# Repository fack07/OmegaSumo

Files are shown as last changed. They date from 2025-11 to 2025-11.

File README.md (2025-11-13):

# 🤖 Robô Lutador de Sumô Autônomo de 3 kg

Este repositório contém o projeto **Omega Sumo**, um robô autônomo de sumô de 3 kg, desenvolvido como parte do **Trabalho de Conclusão de Curso (TCC)** em Engenharia de Computação da UTFPR – Campus Pato Branco.

O projeto aborda a **atualização de hardware e software** do robô, com foco na implementação de um **sistema supervisório baseado em SED (Sistemas a Eventos Discretos)**, visando estratégias eficientes e melhoria de desempenho em combate.

---

## ⚙️ Estrutura do Repositório

| Pasta | Descrição |
|---|---|
| [`Firmware/`](./Firmware) | Contém o código embarcado para o microcontrolador STM32F407VET6, implementando controle de sensores, motores e o supervisor em tempo real. |
| [`Supervisor/`](./Supervisor) | Contém o modelo supervisório desenvolvido no Supremica (`omega_sumo.wmod`), compactado em `.zip`, reunindo as plantas, especificações e supervisor. |
| [`PCB/`](./PCB) | Projeto eletrônico do robô, incluindo esquemáticos e layout da placa. |

---
## 🧰 Ferramentas Utilizadas
- [Supremica](https://www.supremica.org) – Modelagem e síntese supervisória (uso acadêmico)  
- [STM32CubeIDE](https://www.st.com/en/development-tools/stm32cubeide.html) – Desenvolvimento e compilação do firmware  
- [Autodesk EAGLE](https://www.autodesk.com/products/eagle/overview) – Desenvolvimento do projeto eletrônico e layout de PCB  
- [GitHub](https://github.com/) – Controle de versão e compartilhamento do projeto  

---

## 📜 Licença e Uso
Este projeto foi desenvolvido para fins **acadêmicos e de pesquisa**.  
Os arquivos gerados pelo Supremica são distribuídos conforme sua licença de uso educativo.  
O código-fonte embarcado e o projeto eletrônico podem ser reutilizados livremente para fins não comerciais, com a devida citação do autor.

---

## 👤 Autor

**Fabio Kinukawa**  
Engenharia de Computação — UTFPR

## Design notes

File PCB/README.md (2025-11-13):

# ⚡ Projeto Eletrônico – Omega Sumo (PCB)

Esta pasta contém o **projeto eletrônico** do robô autônomo de sumô **Omega Sumo**, desenvolvido no contexto do Trabalho de Conclusão de Curso (TCC) em Engenharia de Computação da UTFPR – Câmpus Pato Branco.

O circuito foi projetado no **Autodesk EAGLE 9.x**, abrangendo os módulos de potência, controle e sensores do robô.  
O objetivo do projeto é fornecer uma base estável e modular para o sistema embarcado do robô, compatível com o microcontrolador **STM32F407VET6**.

---

## 🧩 Estrutura dos Arquivos

| Arquivo | Descrição |
|---|---|
| `OmegaSumo.sch` | Esquemático principal do circuito eletrônico, contendo o microcontrolador, drivers de motor, sensores e interfaces de comunicação. |
| `OmegaSumo.brd` | Layout da placa de circuito impresso (PCB), desenvolvido a partir do esquemático. |
| `pcb_top.png` | Imagens 2D e/ou 3D da placa geradas no EAGLE. |
| `pcb_bottom.png` | Imagens 2D e/ou 3D da placa geradas no EAGLE. |
| `OmegaSumo_PCB.zip` | Arquivo compactado contendo todos os arquivos nativos do projeto EAGLE. |

---

## ⚙️ Especificações Técnicas

- **Software:** Autodesk EAGLE 9.x  
- **Camadas:** 2 (dupla face)  
- **Dimensões aproximadas:** conforme layout (otimizado para o chassi do robô Omega Sumo)  
- **Alimentação:** 7,4 V (Li-Po 2S)  
- **Tensão lógica:** 3,3 V  
- **Controlador principal:** STM32F407VET6  
- **Interfaces principais:** sensores IR, sensores de linha, drivers de motor, botão de start, LEDs de status  

---

## 🛠️ Como Abrir o Projeto

1. Instale o **Autodesk EAGLE** (versão 9.x ou superior).  
2. Baixe e extraia o arquivo [`OmegaSumo_PCB.zip`](./OmegaSumo_PCB.zip).  
3. Abra o arquivo `OmegaSumo.sch` no EAGLE.  
4. Verifique o esquemático e sincronize com o layout (`OmegaSumo.brd`) caso necessário.  
5. Gere os arquivos Gerber para fabricação em **File → CAM Processor → Generate Gerbers**.

---

## ⚠️ Boas Práticas de Projeto

- Mantenha trilhas de potência largas (≥ 1 mm para corrente de motor).  
- Utilize planos de terra (`GND Plane`) para reduzir ruído e interferência.  
- Separe áreas de potência e lógica no layout.  
- Verifique a orientação de componentes polarizados (diodos, capacitores eletrolíticos, conectores).  
- Sempre execute o **DRC (Design Rule Check)** antes da geração dos Gerbers.

---

## 📜 Licença

Este projeto é distribuído para **fins acadêmicos e de pesquisa**, sendo permitido seu uso como referência em estudos e trabalhos relacionados a sistemas embarcados e robótica móvel.  
É proibido o uso comercial sem autorização do autor.

---

## ✍️ Autor

**Fabio Kinukawa**  
Trabalho de Conclusão de Curso – Engenharia de Computação  
UTFPR – Universidade Tecnológica Federal do Paraná  
Equipe: **PatoBots**

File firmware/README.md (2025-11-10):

# 🧠 Firmware – Robô de Sumô Autônomo (Omega Sumo)

Este diretório contém o **firmware embarcado** desenvolvido para o robô de sumô autônomo de 3 kg.  
O código foi implementado em **C** utilizando o **STM32CubeIDE**, com foco em controle de motores, leitura de sensores e execução das ações determinadas pelo supervisor.

---

## ⚙️ Estrutura
- `Core/` – Código principal gerado pelo CubeIDE (funções do sistema embarcado).  
- `Drivers/` – Bibliotecas de periféricos do STM32.  
- `Src/` e `Inc/` – Arquivos de código-fonte e cabeçalhos do projeto.  
- `STM32F407VETX_FLASH.ld` – Script de linkagem do microcontrolador.  

---

## 🧩 Plataforma
- **Microcontrolador:** STM32F407VET6  
- **IDE:** STM32CubeIDE  
- **Linguagem:** C  
- **Compilador:** ARM GCC  
- **Memória ocupada:** ~352 KB de Flash  

---

## 🔗 Integração com o Supervisor
O firmware implementa uma **máquina de estados Meely** gerada a partir do autômato supervisor, compilada e integrada ao código principal.  
A comunicação entre o supervisor e o firmware ocorre por meio de variáveis de evento (entradas e saídas do sistema).

---

## 🧰 Compilação e Gravação
1. Abra o projeto no **STM32CubeIDE**.  
2. Selecione a placa alvo `STM32F407VET6`.  
3. Compile (`Project → Build Project`).  
4. Faça o upload via **ST-LINK/V2** ou programador compatível.

---

## 📄 Licença
Uso educacional e acadêmico.  
Parte do código foi gerado automaticamente pelo STM32CubeIDE.  
Distribuição permitida apenas para fins de pesquisa e documentação.

---

## ✍️ Autor
**Fabio Kinukawa**  
Trabalho de Conclusão de Curso – Engenharia de Computação  
UTFPR – Universidade Tecnológica Federal do Paraná
Campus Pato Branco

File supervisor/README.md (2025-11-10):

# 🧩 Supervisor – Controle Supervisório (Omega Sumo)

Este diretório contém o **modelo supervisório completo** do robô de sumô autônomo de 3 kg, desenvolvido como parte do Trabalho de Conclusão de Curso de Engenharia de Computação (UTFPR).

---

## ⚙️ Descrição
O arquivo principal `omega_sumo.wmod` foi criado utilizando o software **Supremica** e reúne toda a modelagem do sistema, incluindo:

- **Plantas**: modelagem modular dos componentes do robô;  
- **Especificações**: definição das regras e estratégias de controle;  
- **Supervisor**: resultado da **síntese supervisória** após a composição síncrona entre plantas e especificações.

O modelo é usado para gerar o **supervisor implementável**, posteriormente convertido para uma **máquina de estados Moore** e integrado ao firmware do microcontrolador STM32.

---

## 🧠 Ferramenta Utilizada
- **Supremica** – Software para modelagem e análise de sistemas a eventos discretos (uso acadêmico e de pesquisa).  

---

## 🧩 Formato do Arquivo
- `omega_sumo.wmod` – Projeto do Supremica contendo todos os autômatos do sistema.

O arquivo pode ser aberto diretamente no Supremica para visualização, edição e execução da síntese supervisória.

---

## 📜 Observação de Licença
O modelo foi desenvolvido com o Supremica, software **gratuito para uso acadêmico e de pesquisa**.  
Nenhum componente proprietário do Supremica é distribuído neste repositório.

---

## ✍️ Autor
**Fabio Kinukawa**  
Trabalho de Conclusão de Curso – Engenharia de Computação  
UTFPR – Universidade Tecnológica Federal do Paraná
Campus Pato Branco

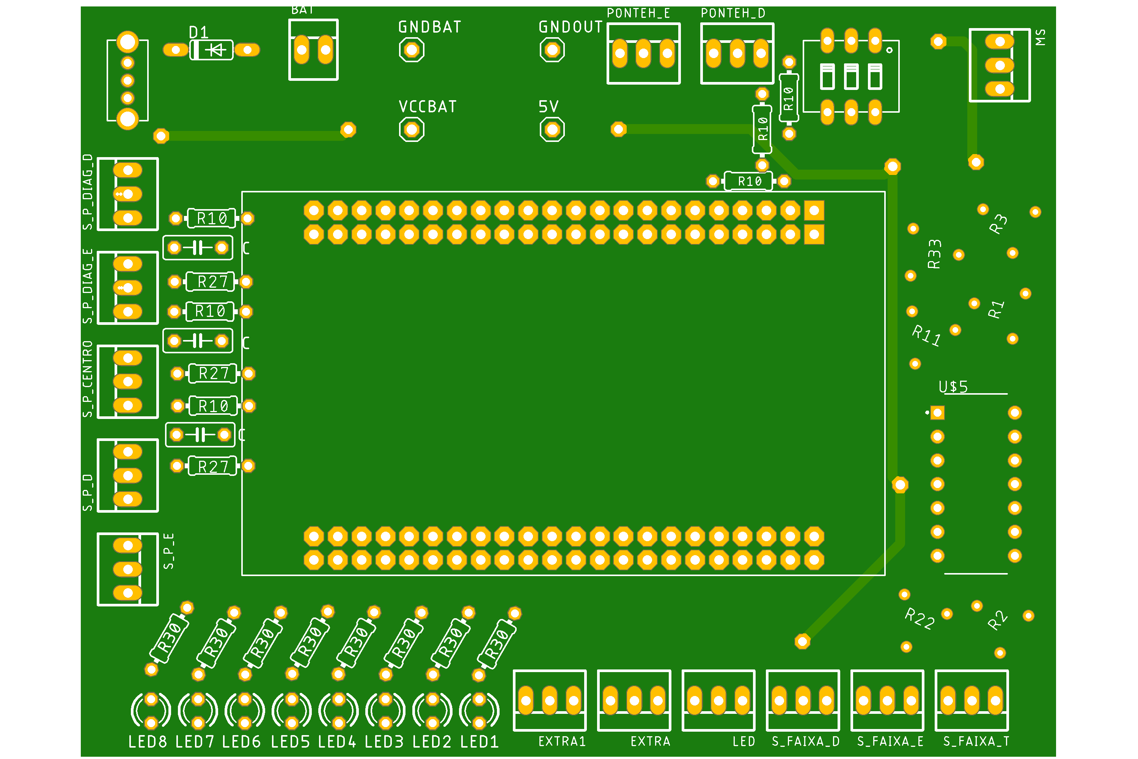
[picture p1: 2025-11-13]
PCB/pcb_top.png

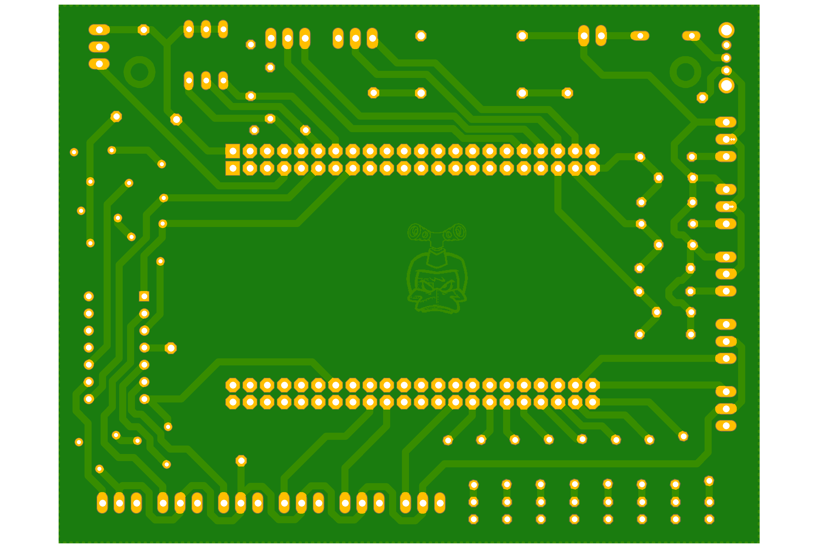
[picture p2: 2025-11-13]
PCB/pcb_bottom.png

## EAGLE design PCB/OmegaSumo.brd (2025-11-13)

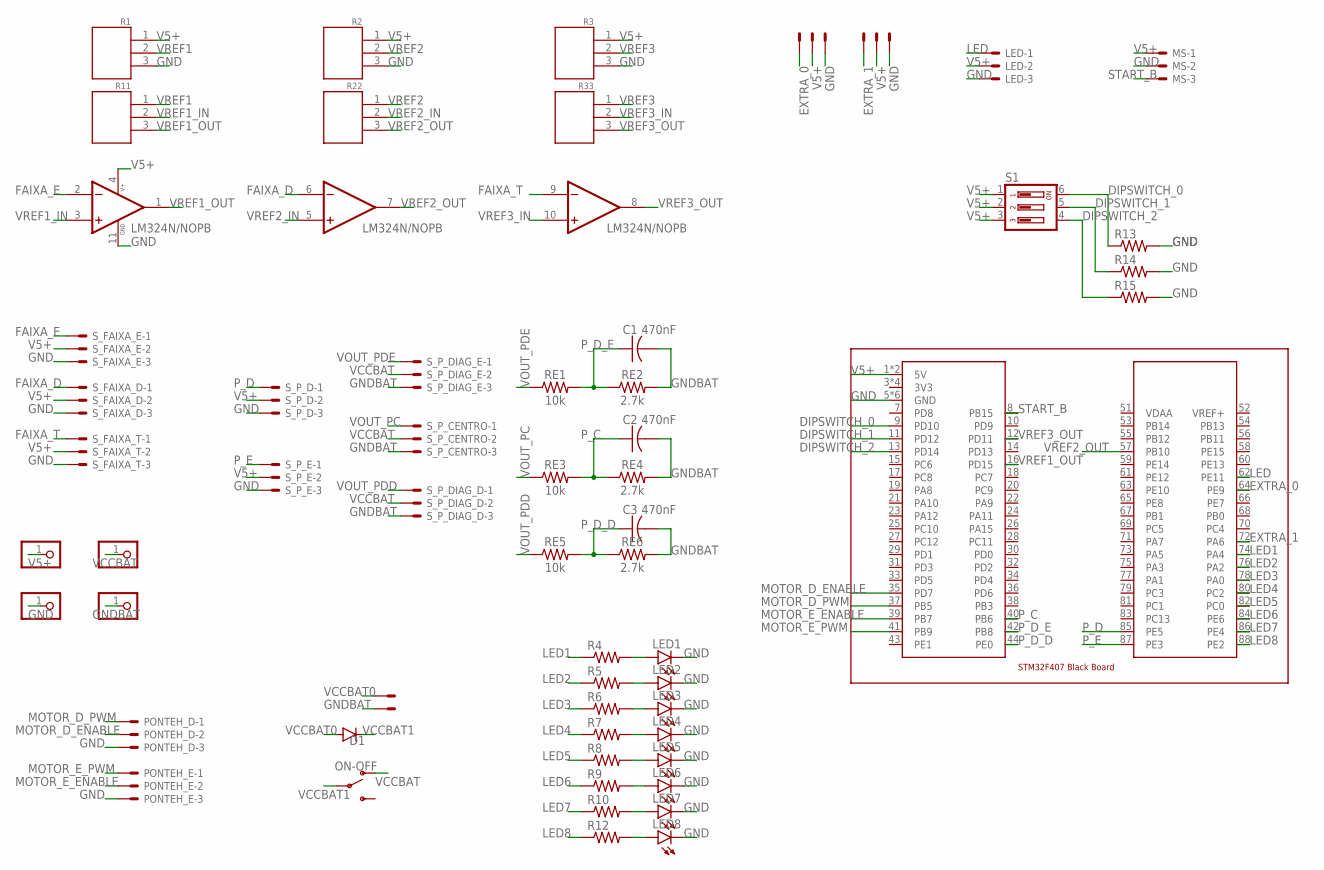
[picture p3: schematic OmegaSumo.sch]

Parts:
5V: PINHD-1X1; 1X01
BAT: 22-23-2021
C1, C2, C3: 470nF; C050-025X075
D1: 1N4148DO35-7; DO35-7
EXTRA, EXTRA1: 22-23-2031
GNDBAT: PINHD-1X1; 1X01
GNDOUT: PINHD-1X1; 1X01
LED: 22-23-2031
LED1, LED2, LED3, LED4, LED5, LED6, LED7, LED8: LED3MM
MS: 22-23-2031
ON-OFF: SWITCH-SPDT-PTH-8.6X4.3MM-LOCK; SWITCH_SPDT_8.6X4.3MM_LOCK
PONTEH_D: 22-23-2031
PONTEH_E: 22-23-2031
R1, R2, R3, R11, R22, R33: RM065
R4, R5, R6, R7, R8, R9, R10, R12, R13, R14, R15: R-US_0204/7; 0204/7
RE1, RE3, RE5: 10k; 0204/7
RE2, RE4, RE6: 2.7k; 0204/7
S1: DIP03YL
S_FAIXA_D: 22-23-2031
S_FAIXA_E: 22-23-2031
S_FAIXA_T: 22-23-2031
S_P_CENTRO: 22-23-2031
S_P_D: 22-23-2031
S_P_DIAG_D: 22-23-2031
S_P_DIAG_E: 22-23-2031
S_P_E: 22-23-2031
U$5: LM324N/NOPB; DIP825W47P254L1917H533Q14
U$6: LIB1BLACK_BOARD; STM32F407
VCCBAT: PINHD-1X1; 1X01

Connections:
DIPSWITCH_0: R13.1, S1.6, U$6.9 (PD10)
DIPSWITCH_1: R14.1, S1.5, U$6.11 (PD12)
DIPSWITCH_2: R15.1, S1.4, U$6.13 (PD14)
EXTRA_0: EXTRA.1, U$6.64 (PE9)
EXTRA_1: EXTRA1.1, U$6.72 (PA6)
FAIXA_D: S_FAIXA_D.1, U$5.6 (2IN-)
FAIXA_E: S_FAIXA_E.1, U$5.2 (1IN-)
FAIXA_T: S_FAIXA_T.1, U$5.9 (3IN-)
GND: EXTRA.3, EXTRA1.3, GNDOUT.1, LED.3, LED1.K (C), LED2.K (C), LED3.K (C), LED4.K (C), LED5.K (C), LED6.K (C), LED7.K (C), LED8.K (C), MS.2, PONTEH_D.3, PONTEH_E.3, R1.3, R2.3, R3.3, R13.2, R14.2, R15.2, S_FAIXA_D.3, S_FAIXA_E.3, S_FAIXA_T.3, S_P_D.3, S_P_E.3, U$5.11 (GND), U$6.5 (GND), U$6.6 (GND), U$6.47 (GND), U$6.48 (GND), U$6.49 (GND), U$6.50 (GND)
GNDBAT: BAT.2, C1.2, C2.2, C3.2, GNDBAT.1, RE2.2, RE4.2, RE6.2, S_P_CENTRO.3, S_P_DIAG_D.3, S_P_DIAG_E.3
LED: LED.1, U$6.62 (PE11)
LED1: R4.1, U$6.74 (PA4)
LED2: R5.1, U$6.76 (PA2)
LED3: R6.1, U$6.78 (PA0)
LED4: R7.1, U$6.80 (PC2)
LED5: R8.1, U$6.82 (PC0)
LED6: R9.1, U$6.84 (PE6)
LED7: R10.1, U$6.86 (PE4)
LED8: R12.1, U$6.88 (PE2)
MOTOR_D_ENABLE: PONTEH_D.2, U$6.35 (PD7)
MOTOR_D_PWM: PONTEH_D.1, U$6.37 (PB5)
MOTOR_E_ENABLE: PONTEH_E.2, U$6.39 (PB7)
MOTOR_E_PWM: PONTEH_E.1, U$6.41 (PB9)
unnamed: LED1.A, R4.2
unnamed: LED2.A, R5.2
unnamed: LED3.A, R6.2
unnamed: LED4.A, R7.2
unnamed: LED5.A, R8.2
unnamed: LED6.A, R9.2
unnamed: LED7.A, R10.2
unnamed: LED8.A, R12.2
P_C: C2.1, RE3.2, RE4.1, U$6.40 (PB6)
P_D: S_P_D.1, U$6.85 (PE5)
P_D_D: C3.1, RE5.2, RE6.1, U$6.44 (PE0)
P_D_E: C1.1, RE1.2, RE2.1, U$6.42 (PB8)
P_E: S_P_E.1, U$6.87 (PE3)
START_B: MS.3, U$6.8 (PB15)
V5+: 5V.1, EXTRA.2, EXTRA1.2, LED.2, MS.1, R1.1, R2.1, R3.1, S1.1, S1.2, S1.3, S_FAIXA_D.2, S_FAIXA_E.2, S_FAIXA_T.2, S_P_D.2, S_P_E.2, U$5.4 (V+), U$6.1 (5V), U$6.2 (5V)
VCCBAT: ON-OFF.1 (O), S_P_CENTRO.2, S_P_DIAG_D.2, S_P_DIAG_E.2, VCCBAT.1
VCCBAT0: BAT.1, D1.A
VCCBAT1: D1.C, ON-OFF.2
VOUT_PC: RE3.1, S_P_CENTRO.1
VOUT_PDD: RE5.1, S_P_DIAG_D.1
VOUT_PDE: RE1.1, S_P_DIAG_E.1
VREF1: R1.2, R11.1
VREF1_IN: R11.2, U$5.3 (1IN+)
VREF1_OUT: R11.3, U$5.1 (1OUT), U$6.16 (PD15)
VREF2: R2.2, R22.1
VREF2_IN: R22.2, U$5.5 (2IN+)
VREF2_OUT: R22.3, U$5.7 (2OUT), U$6.57 (PB10)
VREF3: R3.2, R33.1
VREF3_IN: R33.2, U$5.10 (3IN+)
VREF3_OUT: R33.3, U$5.8 (3OUT), U$6.12 (PD11)

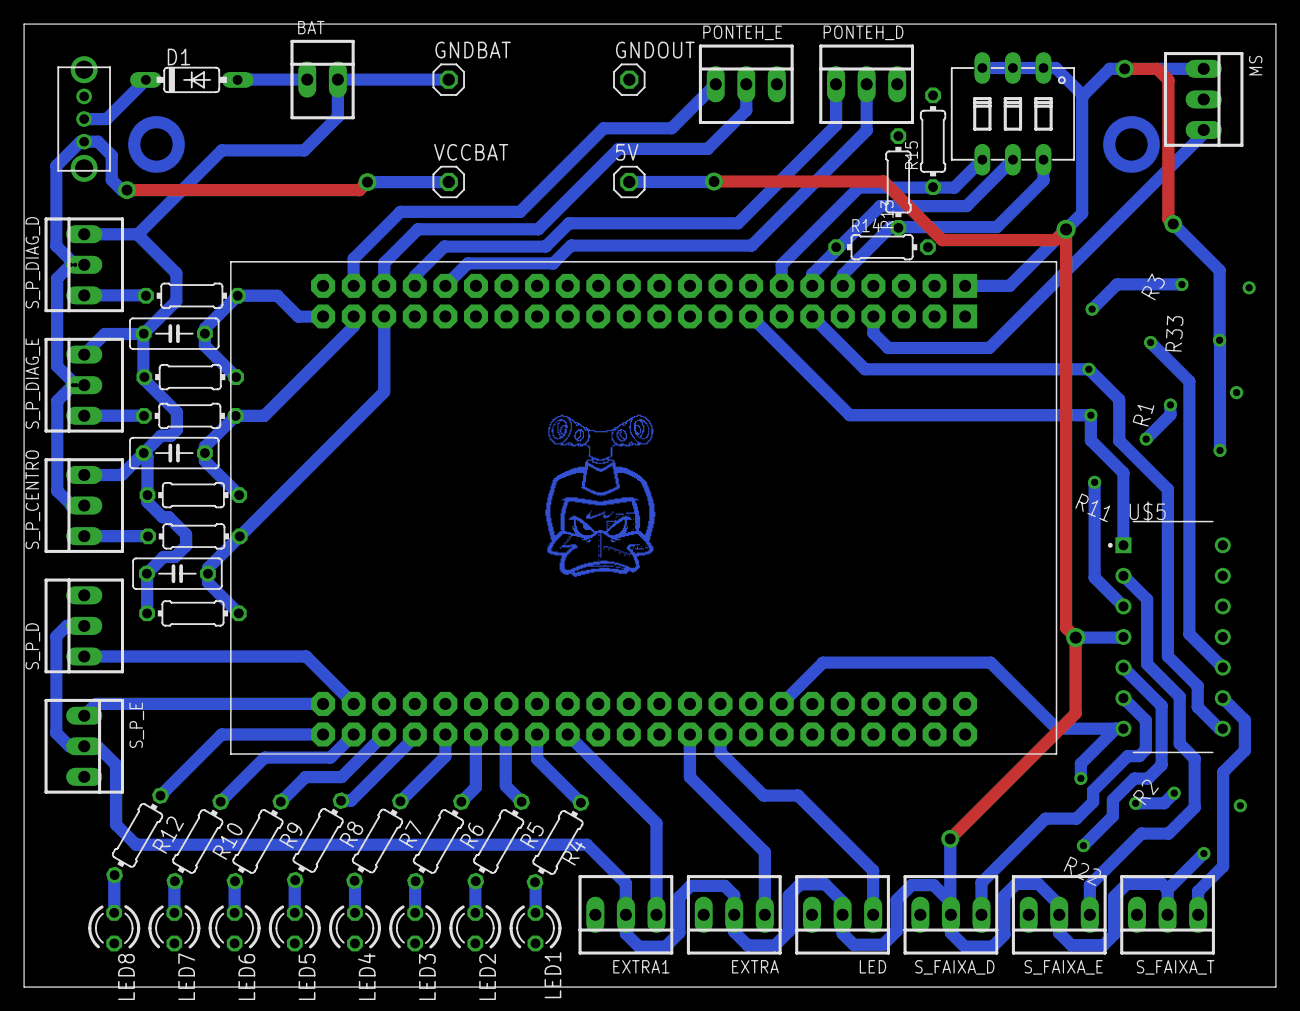
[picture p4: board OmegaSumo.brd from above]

Board: 2 copper layers, 104.0 x 80.0 mm, 58 parts (0 on the bottom side), 53 nets.

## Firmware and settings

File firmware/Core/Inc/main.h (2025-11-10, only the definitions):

#define LED1_Pin GPIO_PIN_2
#define LED1_GPIO_Port GPIOE
#define PRESENCA5_Pin GPIO_PIN_3
#define PRESENCA5_GPIO_Port GPIOE
#define PRESENCA5_EXTI_IRQn EXTI3_IRQn
#define LED2_Pin GPIO_PIN_4
#define LED2_GPIO_Port GPIOE
#define PRESENCA1_Pin GPIO_PIN_5
#define PRESENCA1_GPIO_Port GPIOE
#define PRESENCA1_EXTI_IRQn EXTI9_5_IRQn
#define LED3_Pin GPIO_PIN_6
#define LED3_GPIO_Port GPIOE
#define LED4_Pin GPIO_PIN_0
#define LED4_GPIO_Port GPIOC
#define LED5_Pin GPIO_PIN_2
#define LED5_GPIO_Port GPIOC
#define LED6_Pin GPIO_PIN_0
#define LED6_GPIO_Port GPIOA
#define LED7_Pin GPIO_PIN_2
#define LED7_GPIO_Port GPIOA
#define LED8_Pin GPIO_PIN_4
#define LED8_GPIO_Port GPIOA
#define BANDEIRA_Pin GPIO_PIN_6
#define BANDEIRA_GPIO_Port GPIOA
#define FAIXA2_Pin GPIO_PIN_10
#define FAIXA2_GPIO_Port GPIOB
#define FAIXA2_EXTI_IRQn EXTI15_10_IRQn
#define MICROSTART_Pin GPIO_PIN_15
#define MICROSTART_GPIO_Port GPIOB
#define DIPS0_Pin GPIO_PIN_10
#define DIPS0_GPIO_Port GPIOD
#define FAIXA3_Pin GPIO_PIN_11
#define FAIXA3_GPIO_Port GPIOD
#define FAIXA3_EXTI_IRQn EXTI15_10_IRQn
#define DIPS1_Pin GPIO_PIN_12
#define DIPS1_GPIO_Port GPIOD
#define DIPS2_Pin GPIO_PIN_14
#define DIPS2_GPIO_Port GPIOD
#define FAIXA1_Pin GPIO_PIN_15
#define FAIXA1_GPIO_Port GPIOD
#define FAIXA1_EXTI_IRQn EXTI15_10_IRQn
#define MOTOR_D_ENABLE_Pin GPIO_PIN_7
#define MOTOR_D_ENABLE_GPIO_Port GPIOD
#define MOTOR_E_ENABLE_Pin GPIO_PIN_5
#define MOTOR_E_ENABLE_GPIO_Port GPIOB
#define PRESENCA3_Pin GPIO_PIN_6
#define PRESENCA3_GPIO_Port GPIOB
#define PRESENCA3_EXTI_IRQn EXTI9_5_IRQn
#define PRESENCA2_Pin GPIO_PIN_8
#define PRESENCA2_GPIO_Port GPIOB
#define PRESENCA2_EXTI_IRQn EXTI9_5_IRQn
#define PRESENCA4_Pin GPIO_PIN_0
#define PRESENCA4_GPIO_Port GPIOE
#define PRESENCA4_EXTI_IRQn EXTI0_IRQn

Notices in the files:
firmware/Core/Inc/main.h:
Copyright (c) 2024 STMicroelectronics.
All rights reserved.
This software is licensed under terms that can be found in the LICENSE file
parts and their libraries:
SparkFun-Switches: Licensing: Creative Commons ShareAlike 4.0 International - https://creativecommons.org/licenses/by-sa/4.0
